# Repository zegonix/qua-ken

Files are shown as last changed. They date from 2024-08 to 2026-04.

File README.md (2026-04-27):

**This repository has been moved to [another git server](https://git.krampf.ch/zegonix/qua-ken).**

# qua-ken
this repository holds the design resources for the open source keyboard 'qua-ken'. The qua-ken is heavily inspired by [Josef Adamčík](https://github.com/josefadamcik)'s [Sofle](https://github.com/josefadamcik/SofleKeyboard) and copies its layout. The qua-ken is basically a Sofle modified to meet my custom keyboard standards. The PCB is split into main board and daughter board which holds the connectors. The qua-ken uses more a powerful ARM controller with much more program memory allowing the use of more software features. For the connection of the two halves a 4P4C connector is used as the TRRS connector shorts some of the lines when plugging/unplugging the cable. Currently planned are PCB silicone dumbbell gasket mount and plate top mount. The case is planned as screwless design opening from the top for ease of access. I also think about using the ball catch system gaining popularity, but since I have no experience with mechanical design, I am unsure whether I can manage that in a reasonable amount of revisions.

# Status
~~I just started and am currently working on the PCB. Once the PCB is tested, I will start with the case.~~
I just got the PCBs, it works perfectly fine appart from the encoders, which only work if the left half is master (connected to the computer). I am now starting with the case design and will fix the encoders at some point (just software).

# Licensing
Software (QMK) is licensed under GPL 2.0, With PCB and case designs you are free to do as you will.

# Can you buy this keyboard when it's finished?
Yes and No. I will not open shop and sell the keyboard, but the resources are free and open, so you can order all the parts yourself.

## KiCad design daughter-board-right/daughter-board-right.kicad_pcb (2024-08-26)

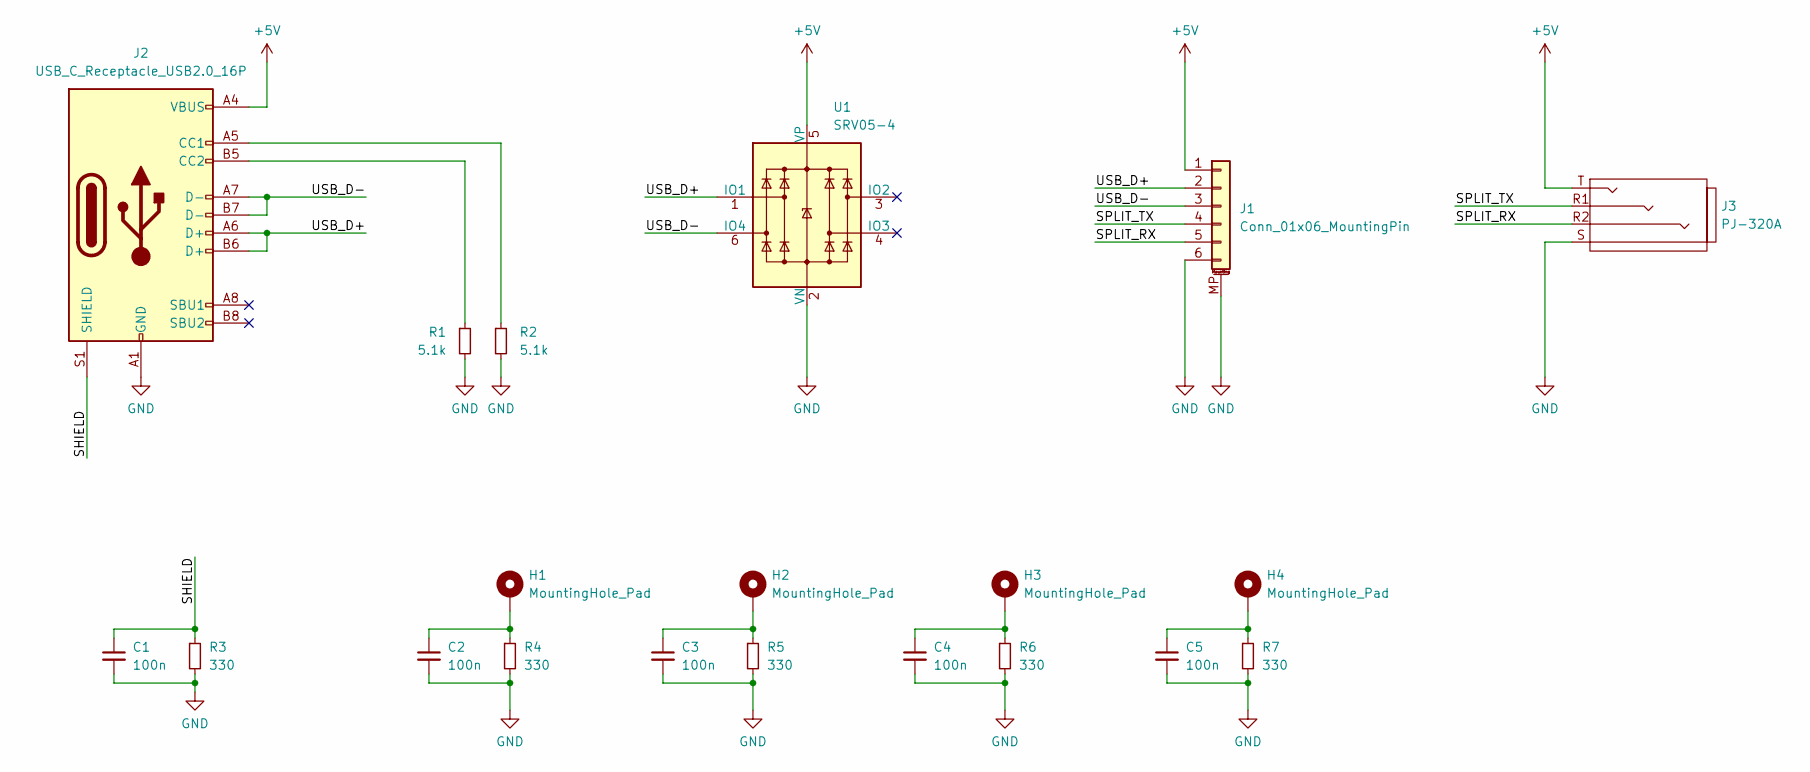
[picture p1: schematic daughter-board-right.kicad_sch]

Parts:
C1, C2, C3, C4, C5: 100n; C_0603_1608Metric
H1, H2, H3, H4: MountingHole_Pad; MountingHole_2.2mm_M2_DIN965_Pad_TopBottom
J1: Conn_01x06_MountingPin; JST_SH_SM06B-SRSS-TB_1x06-1MP_P1.00mm_Horizontal
J2: USB_C_Receptacle_USB2.0_16P; USB_C_Receptacle_HRO_TYPE-C-31-M-12
J3: PJ-320A; TRRS_Receptable
R1, R2: 5.1k; R_0603_1608Metric
R3, R4, R5, R6, R7: 330; R_0603_1608Metric
U1: SRV05-4; SOT-23-6-routable

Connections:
+5V: J1.1, J2.A4 (VBUS), J2.A9 (VBUS), J2.B4 (VBUS), J2.B9 (VBUS), J3.T, U1.5 (VP)
/SHIELD: C1.1, J2.S1 (SHIELD), R3.1
/SPLIT_RX: J1.5, J3.R2
/SPLIT_TX: J1.4, J3.R1
/USB_D+: J1.2, J2.A6 (D+), J2.B6 (D+), U1.1 (IO1)
/USB_D-: J1.3, J2.A7 (D-), J2.B7 (D-), U1.6 (IO4)
GND: C1.2, C2.2, C3.2, C4.2, C5.2, J1.6, J1.MP (MountPin), J2.A1 (GND), J2.A12 (GND), J2.B1 (GND), J2.B12 (GND), J3.S, R1.2, R2.2, R3.2, R4.2, R5.2, R6.2, R7.2, U1.2 (VN)
unnamed: C2.1, H1.1, R4.1
unnamed: C3.1, H2.1, R5.1
unnamed: C4.1, H3.1, R6.1
unnamed: C5.1, H4.1, R7.1
unnamed: J2.A5 (CC1), R2.1
unnamed: J2.B5 (CC2), R1.1

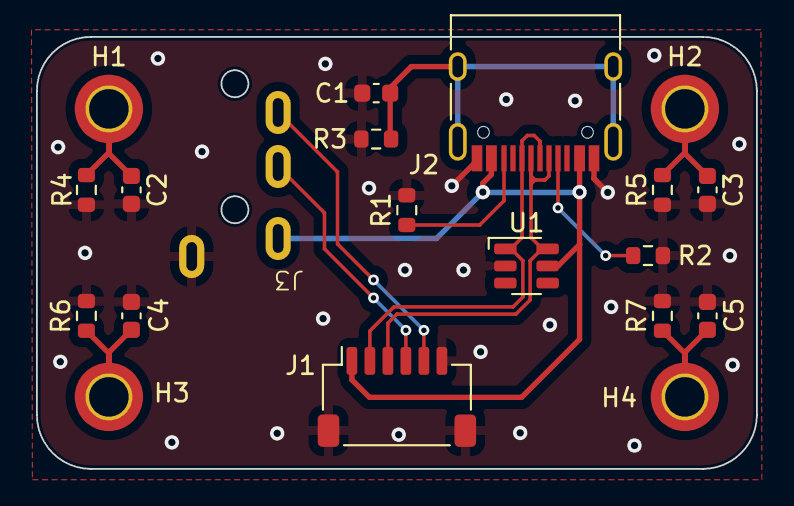
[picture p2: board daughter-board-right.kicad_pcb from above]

Board: 2 copper layers, 40.0 x 24.0 mm, 20 parts (0 on the bottom side), 13 nets.

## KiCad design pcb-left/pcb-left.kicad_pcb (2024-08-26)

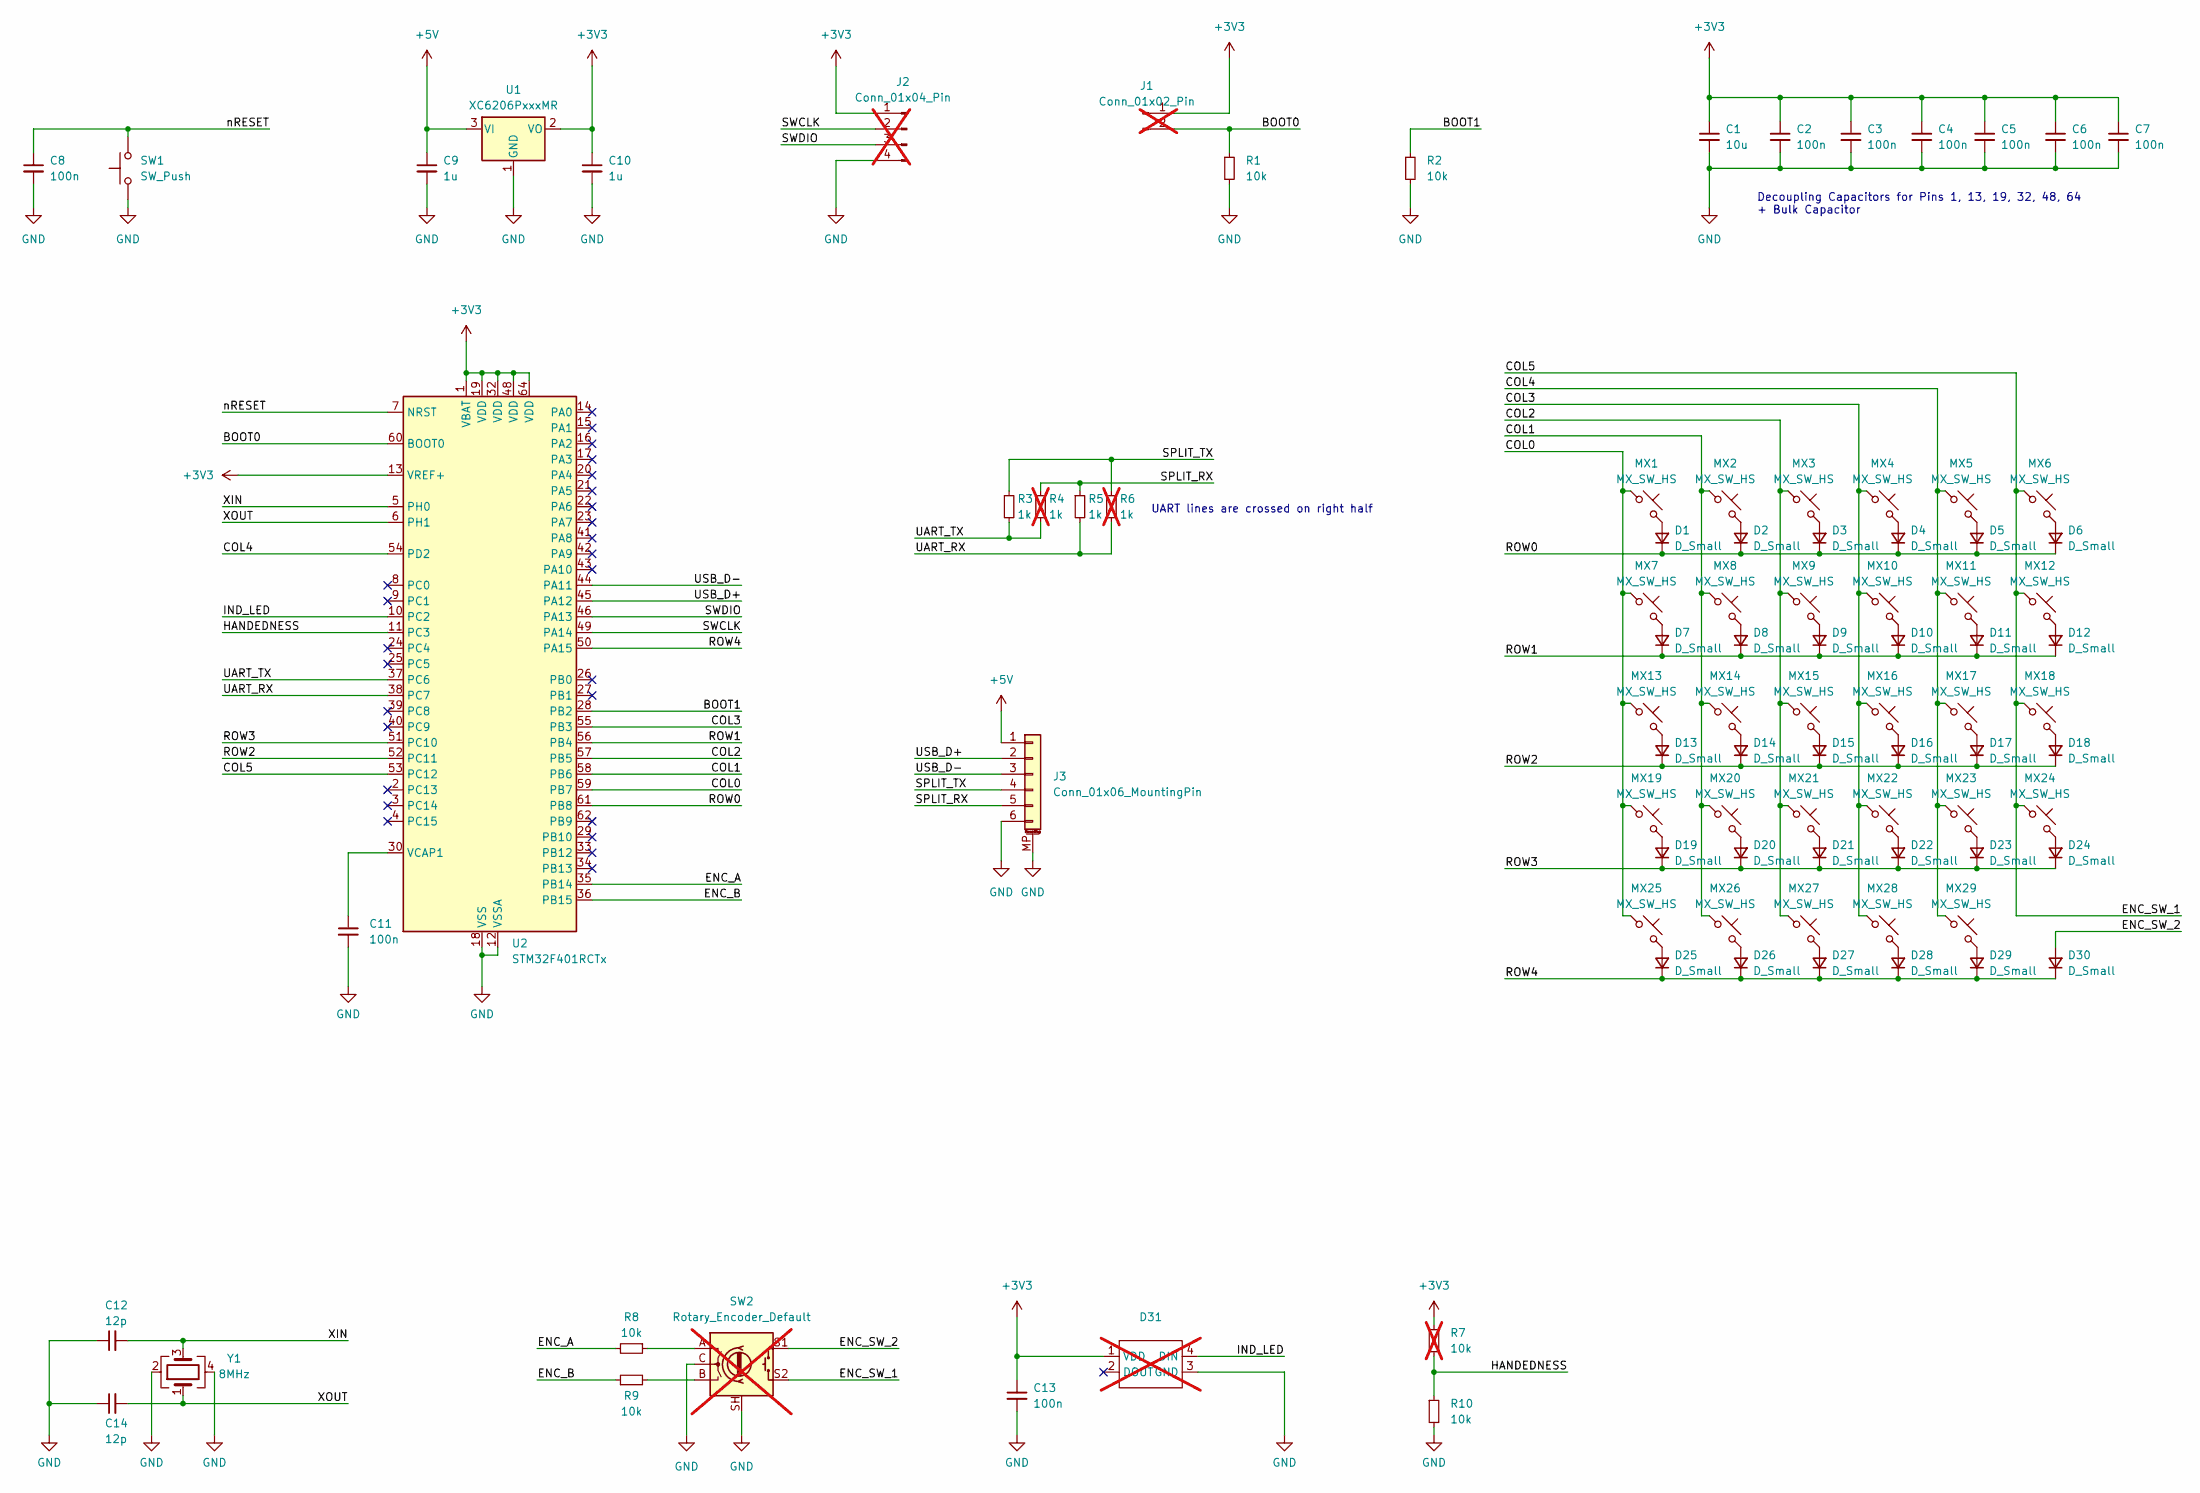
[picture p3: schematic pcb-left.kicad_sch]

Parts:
C1: 10u; C_0603_1608Metric
C2, C3, C4, C5, C6, C7, C8, C11, C13: 100n; C_0603_1608Metric
C9, C10: 1u; C_0603_1608Metric
C12, C14: 12p; C_0603_1608Metric
D1, D2, D3, D4, D5, D6, D7, D8, D9, D10, D11, D12, D13, D14, D15, D16, D17, D18, D19, D20, D21, D22, D23, D24, D25, D26, D27, D28, D29, D30: D_Small; D_SOD-123
D31: SK6812MINI-E_3.2x2.8_reverse_mount; not fitted
J1: Conn_01x02_Pin; PinHeader_1x02_P2.54mm_Vertical; not fitted
J2: Conn_01x04_Pin; PinHeader_1x04_P2.54mm_Vertical; not fitted
J3: Conn_01x06_MountingPin; JST_SH_SM06B-SRSS-TB_1x06-1MP_P1.00mm_Horizontal
MX1, MX2, MX3, MX4, MX5, MX6, MX7, MX8, MX9, MX10, MX11, MX12, MX13, MX14, MX15, MX16, MX17, MX18, MX19, MX20, MX21, MX22, MX23, MX24, MX25, MX26, MX27, MX28, MX29: MX_SW_HS; SW_MX_HS_1u
R1, R2, R8, R9, R10: 10k; R_0603_1608Metric
R3, R5: 1k; R_0603_1608Metric
R4, R6: 1k; R_0402_1005Metric; not fitted
R7: 10k; R_0603_1608Metric; not fitted
SW1: SW_Push; SW_SPST_TL3342
SW2: Rotary_Encoder_Default; RotaryEncoder_Bourns_Vertical_PEC12R-3x17F-Sxxxx; not fitted
U1: XC6206PxxxMR; SOT-23-3
U2: STM32F401RCTx; LQFP-64_10x10mm_P0.5mm
Y1: 8MHz; Crystal_SMD_3225-4Pin_3.2x2.5mm

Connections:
+3V3: C1.1, C2.1, C3.1, C4.1, C5.1, C6.1, C7.1, C10.1, C13.1, D31.1 (VDD), J1.1, J2.1, R7.1, U1.2 (VO), U2.1 (VBAT), U2.13 (VREF+), U2.19 (VDD), U2.32 (VDD), U2.48 (VDD), U2.64 (VDD)
+5V: C9.1, J3.1, U1.3 (VI)
/BOOT0: J1.2, R1.1, U2.60 (BOOT0)
/BOOT1: R2.1, U2.28 (PB2)
/COL0: MX1.1, MX7.1, MX13.1, MX19.1, MX25.1, U2.59 (PB7)
/COL1: MX2.1, MX8.1, MX14.1, MX20.1, MX26.1, U2.58 (PB6)
/COL2: MX3.1, MX9.1, MX15.1, MX21.1, MX27.1, U2.57 (PB5)
/COL3: MX4.1, MX10.1, MX16.1, MX22.1, MX28.1, U2.55 (PB3)
/COL4: MX5.1, MX11.1, MX17.1, MX23.1, MX29.1, U2.54 (PD2)
/COL5: MX6.1, MX12.1, MX18.1, MX24.1, SW2.S2, U2.53 (PC12)
/ENC_A: R8.2, U2.35 (PB14)
/ENC_B: R9.1, U2.36 (PB15)
/ENC_SW_2: D30.2 (A), SW2.S1
/HANDEDNESS: R7.2, R10.1, U2.11 (PC3)
/IND_LED: D31.4 (DIN), U2.10 (PC2)
/ROW0: D1.1 (K), D2.1 (K), D3.1 (K), D4.1 (K), D5.1 (K), D6.1 (K), U2.61 (PB8)
/ROW1: D7.1 (K), D8.1 (K), D9.1 (K), D10.1 (K), D11.1 (K), D12.1 (K), U2.56 (PB4)
/ROW2: D13.1 (K), D14.1 (K), D15.1 (K), D16.1 (K), D17.1 (K), D18.1 (K), U2.52 (PC11)
/ROW3: D19.1 (K), D20.1 (K), D21.1 (K), D22.1 (K), D23.1 (K), D24.1 (K), U2.51 (PC10)
/ROW4: D25.1 (K), D26.1 (K), D27.1 (K), D28.1 (K), D29.1 (K), D30.1 (K), U2.50 (PA15)
/SPLIT_RX: J3.5, R4.1, R5.1
/SPLIT_TX: J3.4, R3.1, R6.1
/SWCLK: J2.2, U2.49 (PA14)
/SWDIO: J2.3, U2.46 (PA13)
/UART_RX: R5.2, R6.2, U2.38 (PC7)
/UART_TX: R3.2, R4.2, U2.37 (PC6)
/USB_D+: J3.2, U2.45 (PA12)
/USB_D-: J3.3, U2.44 (PA11)
/XIN: C12.2, U2.5 (PH0), Y1.3
/XOUT: C14.2, U2.6 (PH1), Y1.1
/nRESET: C8.1, SW1.2, U2.7 (NRST)
GND: C1.2, C2.2, C3.2, C4.2, C5.2, C6.2, C7.2, C8.2, C9.2, C10.2, C11.2, C12.1, C13.2, C14.1, D31.3 (GND), J2.4, J3.6, J3.MP (MountPin), R1.2, R2.2, R10.2, SW1.1, SW2.C, SW2.SH, U1.1 (GND), U2.12 (VSSA), U2.18 (VSS), U2.31 (VSS), U2.47 (VSS), U2.63 (VSS), Y1.2, Y1.4
unnamed: D1.2 (A), MX1.2
unnamed: D2.2 (A), MX2.2
unnamed: D3.2 (A), MX3.2
unnamed: D4.2 (A), MX4.2
unnamed: D5.2 (A), MX5.2
unnamed: D6.2 (A), MX6.2
unnamed: D7.2 (A), MX7.2
unnamed: D8.2 (A), MX8.2
unnamed: D9.2 (A), MX9.2
unnamed: D10.2 (A), MX10.2
unnamed: D11.2 (A), MX11.2
unnamed: D12.2 (A), MX12.2
unnamed: D13.2 (A), MX13.2
unnamed: D14.2 (A), MX14.2
unnamed: D15.2 (A), MX15.2
unnamed: D16.2 (A), MX16.2
unnamed: D17.2 (A), MX17.2
unnamed: D18.2 (A), MX18.2
unnamed: D19.2 (A), MX19.2
unnamed: D20.2 (A), MX20.2
unnamed: D21.2 (A), MX21.2
unnamed: D22.2 (A), MX22.2
unnamed: D23.2 (A), MX23.2
unnamed: D24.2 (A), MX24.2
unnamed: D25.2 (A), MX25.2
unnamed: D26.2 (A), MX26.2
unnamed: D27.2 (A), MX27.2
unnamed: D28.2 (A), MX28.2
unnamed: D29.2 (A), MX29.2
unnamed: R8.1, SW2.A
unnamed: R9.2, SW2.B
unnamed: C11.1, U2.30 (VCAP1)

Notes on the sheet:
Decoupling Capacitors for Pins 1, 13, 19, 32, 48, 64 + Bulk Capacitor
UART lines are crossed on right half

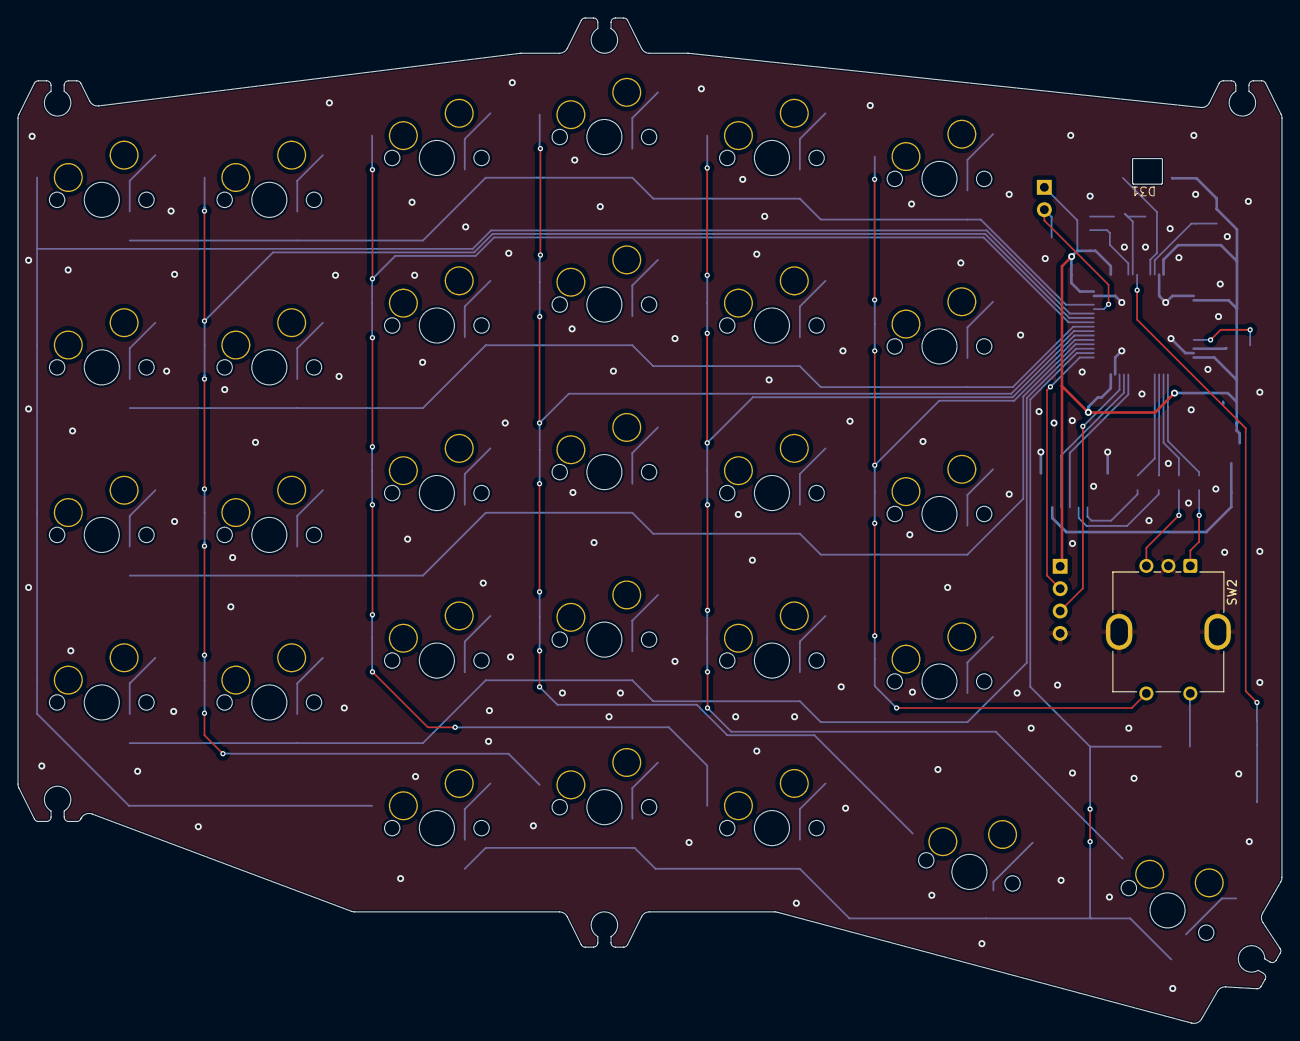
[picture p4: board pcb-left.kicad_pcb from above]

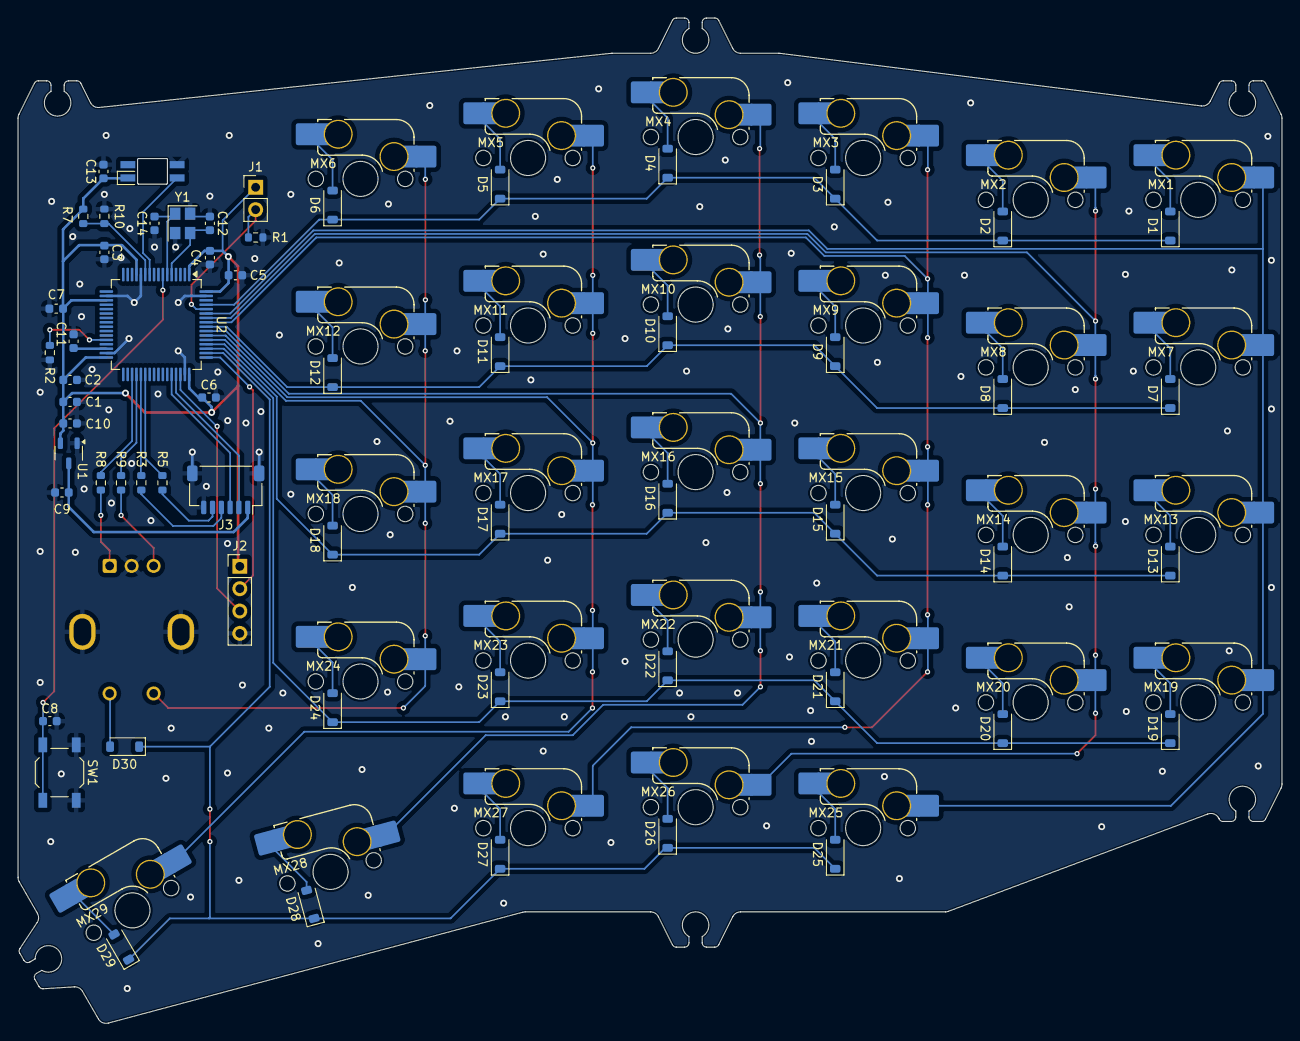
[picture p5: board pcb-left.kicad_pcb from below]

Board: 2 copper layers, 143.7 x 114.3 mm, 90 parts (88 on the bottom side), 64 nets.

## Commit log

2024-03-07 schematics review with scgh
    [daughter-board.kicad_pcb, daughter-board.kicad_sch, pcb-quaken.kicad_pcb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]
2024-03-21 layout ready for review
    [daughter-board.kicad_pcb, daughter-board.kicad_sch, pcb-quaken.kicad_pcb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]
2024-03-30 removed one switch from the thumb cluster
    [pcb-quaken.kicad_pcb, pcb-quaken.kicad_sch]
2024-04-08 implemented findings from layout review (of right half), changed name to pcb-right, created project for left half
    [daughter-board-quaken.kicad_sch, daughter-board.kicad_pcb, daughter-board.kicad_sch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]
2024-04-14 moved daughter board to separate projects for left and right halves fixed layouts of daughter boards..
    [daughter-board.kicad_pcb, daughter-board.kicad_sch, pcb-left.kicad_pcb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]
2024-04-15 added new/renamed folders and files forgotten during last commits finished pcb-left
    [daughter-board-left.kicad_pcb, daughter-board-left.kicad_sch, daughter-board-right.kicad_pcb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]
2024-06-19 quick save
    [daughter-board-left.kicad_pcb, daughter-board-left.kicad_sch, daughter-board-right.kicad_pcb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]
2024-08-26 finalised first version of pcbs for prototype order added openscad file for the left halfs case
    [case-left.scad, daughter-board-left.kicad_pcb, daughter-board-right.kicad_pcb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]
2026-02-22 removed openscad project, the case will be done separately
    [case-left.scad]
2026-04-05 intermediate save
    [pcb-left.kicad_sch, pcb-right.kicad_sch]
